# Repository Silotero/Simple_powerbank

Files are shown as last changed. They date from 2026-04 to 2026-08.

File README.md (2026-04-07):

# Simple_powerbank
This is a portable battery bank capable of being charged and discharged at 15W.

The main IC is the MP2722. It does all the heavy lifting. It advertises that it can be sink or source, but mainly trying to be the source to make sure that phones never become sources for it (Retry source function). It takes care of device plugged in detection at the USB-C port and the unplugging of the device to stop the charge. It also is a buck-boost converter, that allows bucks the charge to be suitable for the batteries, as well as boosting the charge for the USB-C output. It can also detect many faults and advertise them to the Attiny404 microcontroller via I2C, after sending an interrupt signal on its interrupt pin.
There is and AP9101CK6 IC that takes care of battery overcharge, overdischarge and short.

The Attiny404 acts as an additional brain for the MP2722 unlocking more of its functions as well as creating a basic user interface. It operates 5 leds. 4 of them indicate the battery charge and the 5th one lights up to indicate if a problem has been detected by the MP2722.
Since the MP2722 has many registers that change how the device behaves, the Attiny404 must set them according to how the user wants the device to operate. At startup the microcontroller sets up all of the registers and then checks them periodically or after an interrupt to see if the device has for some reason reset. If it detects that it writes to the registers again.

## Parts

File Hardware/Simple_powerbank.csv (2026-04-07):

Reference | Qty | Value | DNP | Exclude from BOM | Exclude from Board | Footprint | Datasheet
C1.C3.C4.C6 | 4 | 22u |  |  |  | Capacitor_SMD:C_0603_1608Metric | ~
C2 | 1 | 22n |  |  |  | Capacitor_SMD:C_0603_1608Metric | ~
C5 | 1 | 1u |  |  |  | Capacitor_SMD:C_0603_1608Metric | ~
C7.C8.C16 | 3 | 100n |  |  |  | Capacitor_SMD:C_0603_1608Metric | ~
C9 | 1 | 4.7u |  |  |  | Capacitor_SMD:C_0603_1608Metric | ~
C11.C12.C15.C19 | 4 | 330u |  |  |  | Capacitor_THT:CP_Radial_D6.3mm_P2.50mm | ~
C13 | 1 | 2.2u |  |  |  | Capacitor_SMD:C_0603_1608Metric | ~
C17.C18 | 2 | 220n |  |  |  | Capacitor_SMD:C_0603_1608Metric | ~
D1.D2.D3.D4 | 4 | LED |  |  |  | LED_SMD:LED_0603_1608Metric | ~
D5 | 1 | Problem_led |  |  |  | LED_SMD:LED_0603_1608Metric | ~
D6 | 1 | SMAJ5.0A |  |  |  | Diode_SMD:D_SMA | https://www.littelfuse.com/media?itemid=75e32973-b177-4ee3-a0ff-cedaf1abdb93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
H1.H4 | 2 | Bat- |  | Wyklucz z BOM |  | MountingHole:MountingHole_2.2mm_M2_DIN965_Pad_TopBottom | ~
H2.H3 | 2 | Bat+ |  | Wyklucz z BOM |  | MountingHole:MountingHole_2.2mm_M2_DIN965_Pad_TopBottom | ~
H5.H6.H7.H8 | 4 | MountingHole_Pad |  | Wyklucz z BOM |  | MountingHole:MountingHole_2.2mm_M2_DIN965_Pad | ~
IC1 | 1 | MP2722GRH-0000-Z |  |  |  | MP2722GRH0000Z | https://www.monolithicpower.com/en/documentview/productdocument/index/version/2/document_type/Datasheet/lang/en/sku/MP2722GRH/document_id/10035/
J2 | 1 | USB_C_Receptacle_USB2.0_16P |  |  |  | Connector_USB:USB_C_Receptacle_GCT_USB4105-xx-A_16P_TopMnt_Horizontal | https://www.usb.org/sites/default/files/documents/usb_type-c.zip
J3 | 1 | Programming |  |  |  | Connector_PinHeader_2.54mm:PinHeader_1x03_P2.54mm_Vertical | ~
L1 | 1 | L |  |  |  | Inductor_SMD:L_10.4x10.4_H4.8 | https://www.tme.eu/pl/details/hci1040-4r3/dlawiki/ferrocore/
Q2.Q3 | 2 | NMOS |  |  |  | Package_SO:SOP-8_3.76x4.96mm_P1.27mm | https://ngspice.sourceforge.io/docs/ngspice-html-manual/manual.xhtml
R1.R2.R6.R7.R8 | 5 | 1M |  |  |  | Resistor_SMD:R_0805_2012Metric | ~
R3.R4.R5.R9 | 4 | 10k |  |  |  | Resistor_SMD:R_0805_2012Metric | ~
R10.R11.R12.R13.R14 | 5 | 1k |  |  |  | Resistor_SMD:R_0805_2012Metric | ~
R15 | 1 | 330 |  |  |  | Resistor_SMD:R_0805_2012Metric | ~
R16 | 1 | 2.7k |  |  |  | Resistor_SMD:R_0805_2012Metric | ~
SW1 | 1 | Reset_button |  |  |  | Connector_PinHeader_1.27mm:PinHeader_1x02_P1.27mm_Vertical | ~
TH1 | 1 | 10K |  |  |  | Connector_PinHeader_1.27mm:PinHeader_1x02_P1.27mm_Vertical | ~
U1 | 1 | AP9101CK6 |  |  |  | Package_TO_SOT_SMD:SOT-23-6 | https://www.diodes.com/assets/Datasheets/AP9101C.pdf
U2 | 1 | ATtiny404-SS |  |  |  | Package_SO:SOIC-14_3.9x8.7mm_P1.27mm | http://ww1.microchip.com/downloads/en/DeviceDoc/50002687A.pdf
U4 | 1 | SRV05-4 |  |  |  | Package_TO_SOT_SMD:SOT-23-6 | http://www.onsemi.com/pub/Collateral/SRV05-4-D.PDF

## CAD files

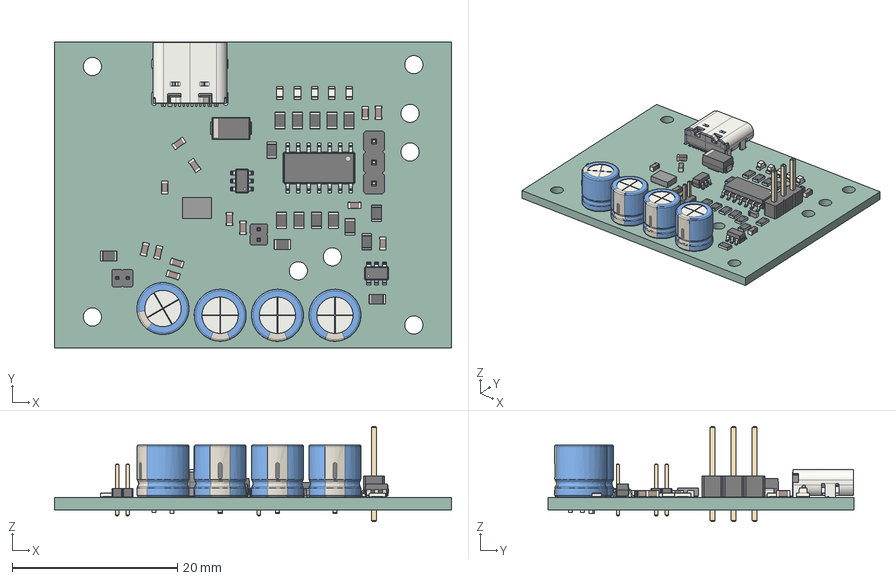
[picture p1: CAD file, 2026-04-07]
Hardware/Simple_powerbank.step
48.0 x 37.0 x 11.5 mm
USB_C_Receptacle_GCT_USB4105-xx-A_16P_TopMnt_Horizontal
R_0805_2012Metric x 16
C_0603_1608Metric x 13
CP_Radial_D6.3mm_P2.50mm x 4
D_SMA
LED_0603_1608Metric x 5
SOIC-14_3.9x8.7mm_P1.27mm
SOT-23-6 x 2
PinHeader_1x02_P1.27mm_Vertical x 2
PinHeader_1x03_P2.54mm_Vertical
Pins
Simple_powerbank_PCB

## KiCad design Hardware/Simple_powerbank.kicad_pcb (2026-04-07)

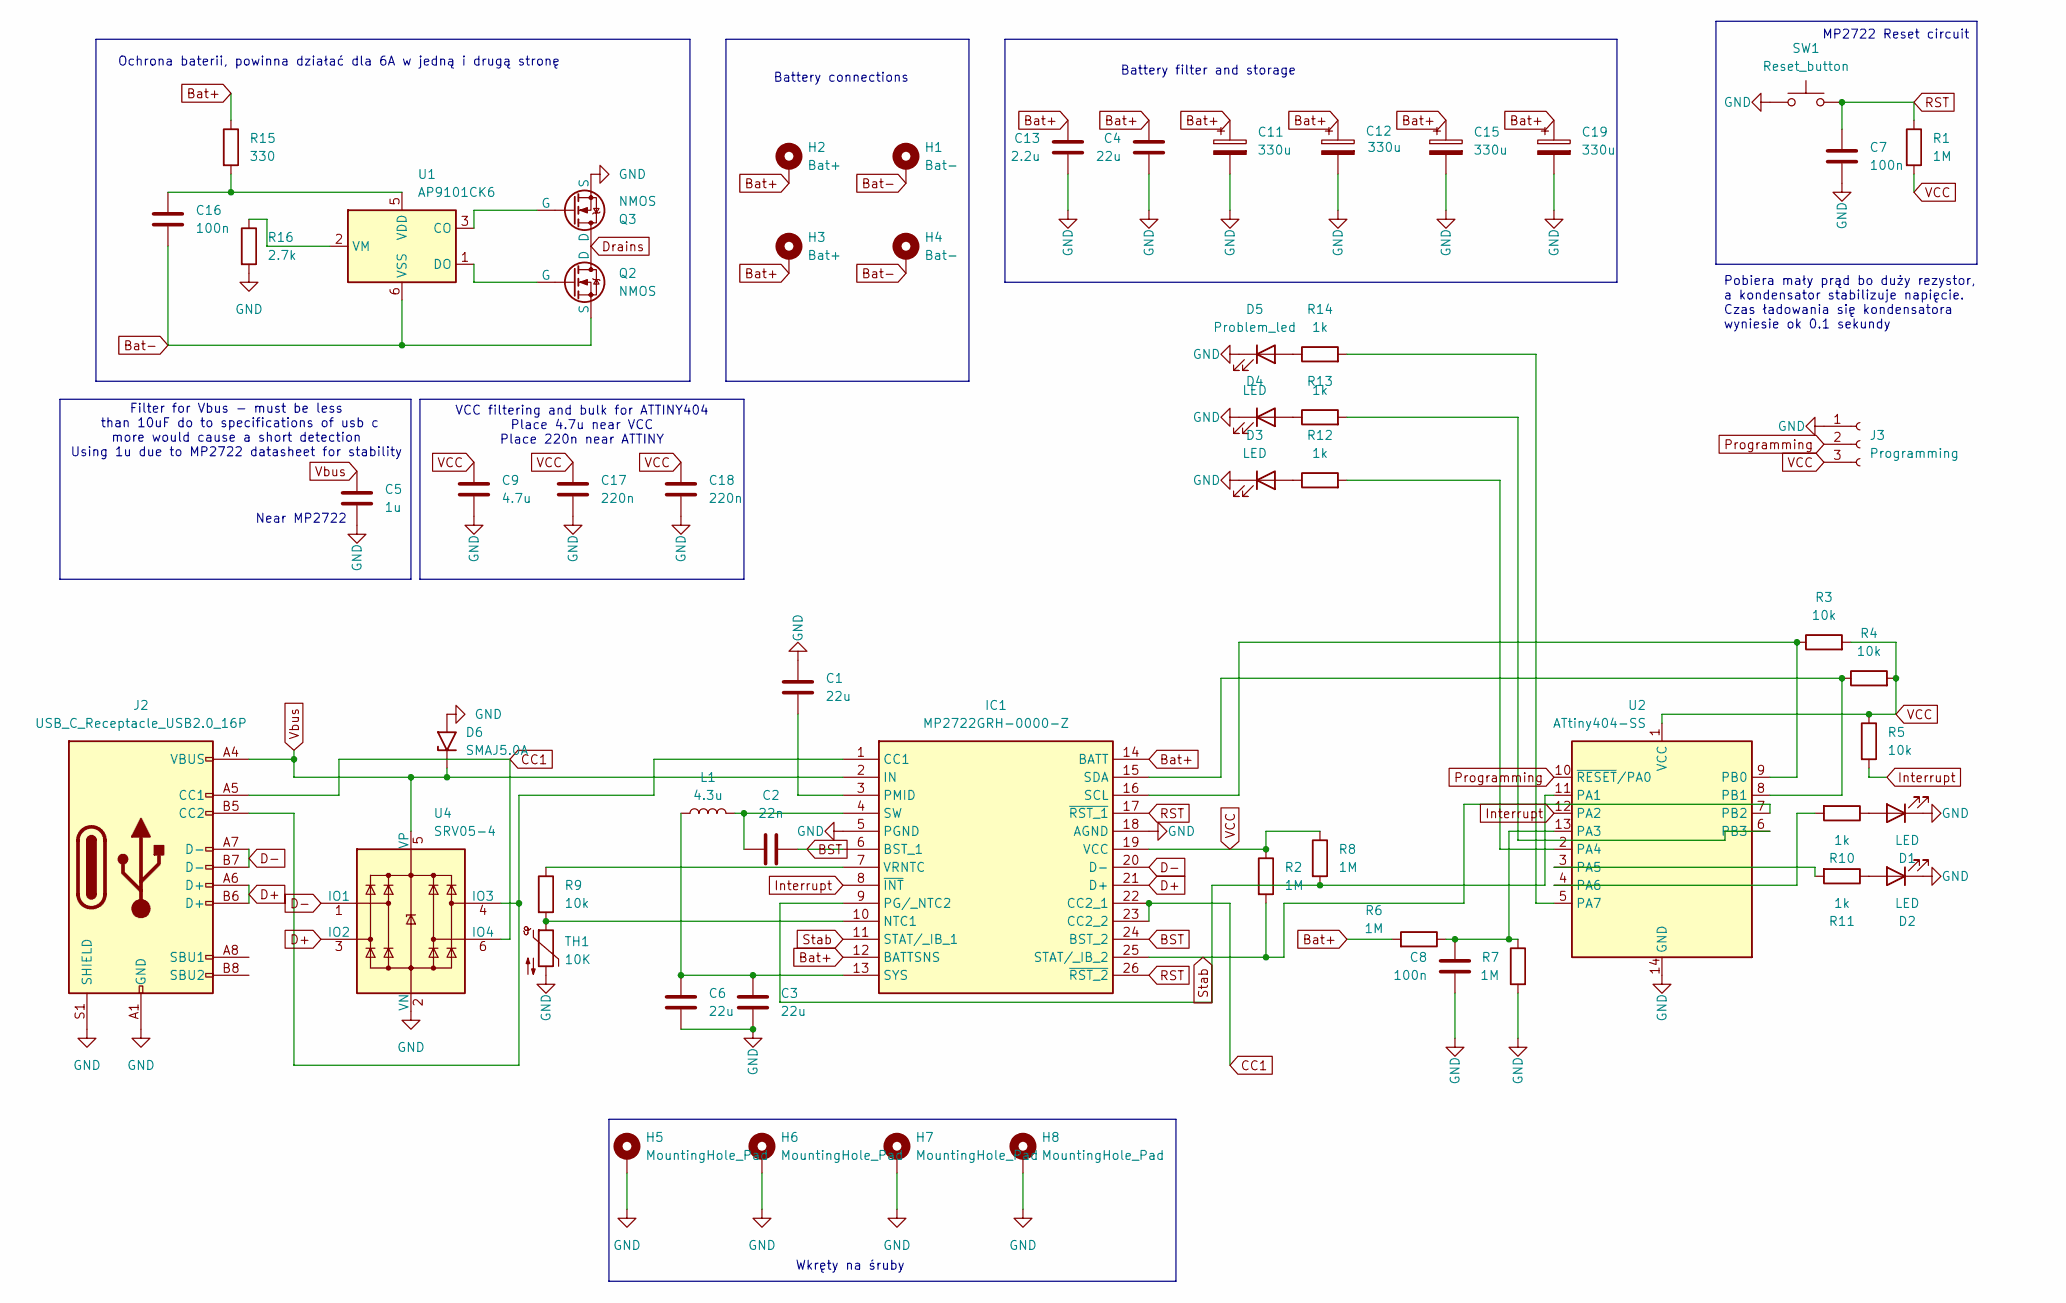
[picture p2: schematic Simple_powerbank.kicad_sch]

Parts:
C1, C3, C4, C6: 22u; C_0603_1608Metric
C2: 22n; C_0603_1608Metric
C5: 1u; C_0603_1608Metric
C7, C8, C16: 100n; C_0603_1608Metric
C9: 4.7u; C_0603_1608Metric
C11, C12, C15, C19: 330u; CP_Radial_D6.3mm_P2.50mm
C13: 2.2u; C_0603_1608Metric
C17, C18: 220n; C_0603_1608Metric
D1, D2, D3, D4: LED; LED_0603_1608Metric
D5: Problem_led; LED_0603_1608Metric
D6: SMAJ5.0A; D_SMA
H1, H4: Bat-; MountingHole_2.2mm_M2_DIN965_Pad_TopBottom
H2, H3: Bat+; MountingHole_2.2mm_M2_DIN965_Pad_TopBottom
H5, H6, H7, H8: MountingHole_Pad; MountingHole_2.2mm_M2_DIN965_Pad
IC1: MP2722GRH-0000-Z; MP2722GRH0000Z; Manufacturer_Part_Number MP2722GRH-0000-Z; Mouser Part Number 946-MP2722GRH-0000-Z
J2: USB_C_Receptacle_USB2.0_16P; USB_C_Receptacle_GCT_USB4105-xx-A_16P_TopMnt_Horizontal
J3: Programming; PinHeader_1x03_P2.54mm_Vertical
L1: 4.3u; L_10.4x10.4_H4.8
Q2, Q3: NMOS; SOP-8_3.76x4.96mm_P1.27mm
R1, R2, R6, R7, R8: 1M; R_0805_2012Metric
R3, R4, R5, R9: 10k; R_0805_2012Metric
R10, R11, R12, R13, R14: 1k; R_0805_2012Metric
R15: 330; R_0805_2012Metric
R16: 2.7k; R_0805_2012Metric
SW1: Reset_button; PinHeader_1x02_P1.27mm_Vertical
TH1: 10K; PinHeader_1x02_P1.27mm_Vertical
U1: AP9101CK6; SOT-23-6
U2: ATtiny404-SS; SOIC-14_3.9x8.7mm_P1.27mm
U4: SRV05-4; SOT-23-6

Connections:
BST: C2.2, IC1.6 (BST_1), IC1.24 (BST_2)
Bat+: C4.2, C11.1, C12.1, C13.2, C15.1, C19.1, H2.1, H3.1, IC1.12 (BATTSNS), IC1.14 (BATT), R6.2, R15.1
Bat-: C16.2, H1.1, H4.1, Q2.3 (S), U1.6 (VSS)
CC1: IC1.22 (CC2_1), IC1.23 (CC2_2), J2.A5 (CC1), U4.6 (IO4)
D+: IC1.21 (D+), J2.A6 (D+), J2.B6 (D+), U4.3 (IO2)
D-: IC1.20 (D-), J2.A7 (D-), J2.B7 (D-), U4.1 (IO1)
Drains: Q2.1 (D), Q3.1 (D)
GND: C1.1, C3.2, C4.1, C5.1, C6.2, C7.2, C8.2, C9.2, C11.2, C12.2, C13.1, C15.2, C17.2, C18.2, C19.2, D1.1 (K), D2.1 (K), D3.1 (K), D4.1 (K), D5.1 (K), D6.2 (A2), H5.1, H6.1, H7.1, H8.1, IC1.5 (PGND), IC1.18 (AGND), J2.A1 (GND), J2.A12 (GND), J2.B1 (GND), J2.B12 (GND), J2.S1 (SHIELD), J3.1, Q3.3 (S), R7.2, R16.2, SW1.1, TH1.2, U2.14 (GND), U4.2 (VN)
Interrupt: IC1.8 (~INT), R5.2, U2.12 (PA2)
unnamed: D1.2 (A), R10.1
unnamed: D2.2 (A), R11.1
unnamed: D3.2 (A), R12.1
unnamed: D4.2 (A), R13.1
unnamed: D5.2 (A), R14.1
unnamed: IC1.1 (CC1), J2.B5 (CC2), U4.4 (IO3)
unnamed: IC1.10 (NTC1), R9.2, TH1.1
unnamed: IC1.9 (PG/_NTC2), R8.2, U2.11 (PA1)
unnamed: C1.2, IC1.3 (PMID)
unnamed: IC1.16 (SCL), R3.1, U2.9 (PB0)
unnamed: IC1.15 (SDA), R4.1, U2.8 (PB1)
unnamed: C2.1, IC1.4 (SW), L1.2
unnamed: C3.1, C6.1, IC1.13 (SYS), L1.1
unnamed: IC1.7 (VRNTC), R9.1
unnamed: Q2.2 (G), U1.1 (DO)
unnamed: Q3.2 (G), U1.3 (CO)
unnamed: C16.1, R15.2, U1.5 (VDD)
unnamed: R16.1, U1.2 (VM)
unnamed: C8.1, R6.1, R7.1, U2.13 (PA3)
unnamed: R12.2, U2.2 (PA4)
unnamed: R11.2, U2.3 (PA5)
unnamed: R10.2, U2.4 (PA6)
unnamed: R14.2, U2.5 (PA7)
unnamed: R13.2, U2.6 (PB3)
Programming: J3.2, U2.10 (~RESET/PA0)
RST: C7.1, IC1.17 (~RST_1), IC1.26 (~RST_2), R1.1, SW1.2
Stab: IC1.11 (STAT/_IB_1), IC1.25 (STAT/_IB_2), R2.2, U2.7 (PB2)
VCC: C9.1, C17.1, C18.1, IC1.19 (VCC), J3.3, R1.2, R2.1, R3.2, R4.2, R5.1, R8.1, U2.1 (VCC)
Vbus: C5.2, D6.1 (A1), IC1.2 (IN), J2.A4 (VBUS), J2.A9 (VBUS), J2.B4 (VBUS), J2.B9 (VBUS), U4.5 (VP)

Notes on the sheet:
Battery filter and storage
Ochrona baterii, powinna działać dla 6A w jedną i drugą stronę
Wkręty na śruby
Battery connections
VCC filtering and bulk for ATTINY404 Place 4.7u near VCC Place 220n near ATTINY
MP2722 Reset circuit
Filter for Vbus - must be less than 10uF do to specifications of usb c more would cause a short detection Using 1u due to MP2722 datasheet for stability
Pobiera mały prąd bo duży rezystor, a kondensator stabilizuje napięcie. Czas ładowania się kondensatora wyniesie ok 0.1 sekundy
Near MP2722

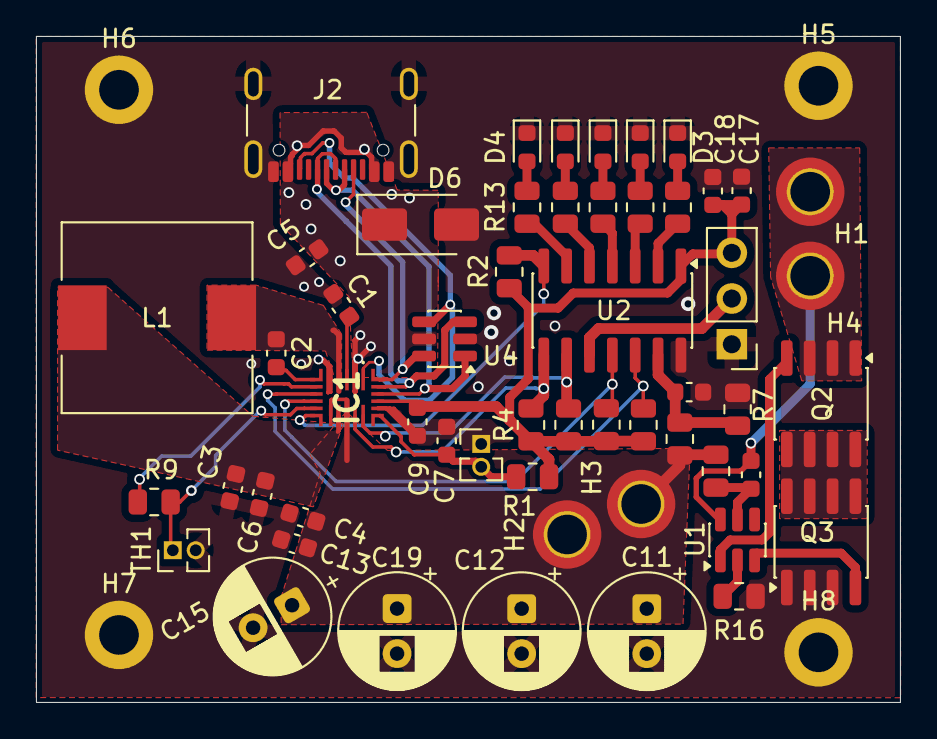
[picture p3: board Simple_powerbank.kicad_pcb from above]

Board: 2 copper layers, 48.0 x 37.0 mm, 58 parts (0 on the bottom side), 38 nets.

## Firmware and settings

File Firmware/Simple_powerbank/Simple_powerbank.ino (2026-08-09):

#include "MP2722.h"
#include <avr/sleep.h>

MP2722 charger;
volatile bool eventDetected = false; // got an interrupt or not

bool faultDetected = false; // read a register, got fault/no fault, used for lighting up fault problem led

const int PIN_BATT  = PIN_PA3;  // Battery divider input
const int Battery_LED_PINS[] = {PIN_PA4, PIN_PA5, PIN_PA6, PIN_PA7}; // LED gpios
const int Problem_LED = PIN_PB3;

// Voltage levels for 1, 2, 3, 4 LEDs
const uint16_t BATT_THRESHOLDS[] = {696, 737, 778, 830}; // Pre-calculated ADC thresholds for: 3.4V, 3.6V, 3.8V, 4.06V

const unsigned long SWITCH_INTERVAL = 2500; // 2500 microseconds = 2.5ms
// Variables for Multiplexing
int currentLedIndex = 0;
unsigned long lastSwitchTime = 0;
unsigned long lastAdcTime = 0;
uint16_t rawAvg = 0;

// The Hardware ISR
// ISR = Interrupt Service Routine
// PORTA_PORT_vect = The hardware address for ANY interrupt on Port A
ISR(PORTA_PORT_vect) {
    // 1. Check WHICH pin fired (Critical if you have multiple interrupts on Port A)
    // We check if the Interrupt Flag (INTFLAGS) for Pin 2 is set, since that is where the interrupt from the MP2722 is connected
    if (PORTA.INTFLAGS & PIN2_bm) {
        
        // 2. Set the eventDetected to true to use it later
        eventDetected = true;

        // 3. Clear the Interrupt Flag (CRITICAL!)
        // Writing '1' to the flag bit aclears it
        // If not cleared, the interrupt will fire again immediately forever.
        PORTA.INTFLAGS = PIN2_bm; 
    }
}

void setup() {
    //Start I2C on the attiny404
    Wire.begin();
    //PORTB.DIRSET = PIN2_bm; // stat pin, read to find out if pinB2
    // Setting up the interrupt
    PORTA.DIRCLR = PIN2_bm; // Assuming INT is on PA2, set up as input
    PORTA.PIN2CTRL = PORT_ISC_FALLING_gc; // to read the falling edge on interrupt pin

    PORTA.DIRSET = PIN4_bm | PIN5_bm | PIN6_bm | PIN7_bm;
    PORTB.DIRSET = PIN3_bm; // Setting up the leds pins as outputs

    PORTA.OUTCLR = PIN4_bm | PIN5_bm | PIN6_bm | PIN7_bm;
    PORTB.OUTCLR = PIN3_bm; // Setting low output for the led pins

    PORTA.DIRCLR = PIN3_bm; // PIN_PA3 set as input, for reading battery voltage divider
    // 1. Set Voltage Reference to Internal 2.5V
    // (Replaces analogReference(INTERNAL2V5))
    VREF.CTRLA |= VREF_ADC0REFSEL_2V5_gc;
    // 2. Configure the ADC Prescaler
    // We want the ADC clock to be between 50kHz and 1.5MHz.
    // Assuming 20MHz CPU clock, DIV32 gives ~625kHz.
    ADC0.CTRLC = ADC_PRESC_DIV16_gc; // or DIV16_gc if running at 10MHz
    // 3. Enable the ADC (10-bit resolution is default)
    ADC0.CTRLA = ADC_ENABLE_bm | ADC_RESSEL_10BIT_gc;

    // 2. Start Charger
    if (charger.wasReset()) {
        charger.begin();
    }

    // setup the sleep workarounds of the attiny404
    set_sleep_mode(SLEEP_MODE_PWR_DOWN); 
}

void loop() {
    static unsigned long last_sleep_check = 0;
    unsigned long current_millis = millis();
    showBatteryLevel();
    // 1. Handle Events
    if (eventDetected) {
        eventDetected = false;
        if (charger.processInterrupt()) {
            faultDetected = true;
        }
        else faultDetected = false;
    }

    if (faultDetected) {
        digitalWrite(Problem_LED, (current_millis / 250) % 2); // Fast blink the problem indicating led
    }

    // 2. Periodically check "Canary" (in case Watchdog reset happened silently)
    static unsigned long lastCheck = 0;
    if (current_millis - lastCheck > 10000) {
        if (charger.wasReset()) {
            charger.begin(); // Re-apply settings
        }
        lastCheck = current_millis;
    }
    
    if (current_millis - last_sleep_check > 15000) {
        if (!charger.isChargingDischarging()) {
            PORTA.OUTCLR = PIN4_bm | PIN5_bm | PIN6_bm | PIN7_bm;
            PORTB.OUTCLR = PIN3_bm;
            charger.gotosleep();
        }
        last_sleep_check = current_millis;
    }
}

void showBatteryLevel() { // this lights up battery indicator leds
    // 1. Read ADC
    // We take a few samples and average them to remove noise
    unsigned long currentMicros = micros();
    if (currentMicros - lastAdcTime >= 500000) { 
        lastAdcTime = currentMicros;
        uint16_t rawSum = 0;
        for(uint8_t i = 0; i < 4; i++) {
            rawSum += readBatteryADC(); // Direct hardware read
        }
        rawAvg = rawSum >> 2;
        if (rawAvg > 850) {
             if (charger.FinishedCharging()) VPORTB.OUT |= PIN3_bm;
        }
    }

    // 3. Update LEDs
    // Workings of the battery indication: the leds gets cycled so only one is actually on at a time, the leds light up based on if the battery level is higher than the set level for the charge. If the charge is below 3.4 the first leds flickers
    if (currentMicros - lastSwitchTime >= SWITCH_INTERVAL) {
        lastSwitchTime = currentMicros;

        currentLedIndex++;
        if (currentLedIndex >= 4) {
            currentLedIndex = 0;
        }

        // 2. Clear ALL LEDs (Atomic & Fast)
        // Instead of looping to find which ones to turn off, just kill them all.
        // LEDs are on PA4, PA5, PA6, PA7
        PORTA.OUTCLR = PIN4_bm | PIN5_bm | PIN6_bm | PIN7_bm;

        // 3. Logic: Should the CURRENT LED be ON?
        bool shouldTurnOn = false;

        // SPECIAL CASE: Critical Low Battery (Blink LED 0)
        if (currentLedIndex == 0 && rawAvg < 696) {
            // ">> 8" divides by 256. "& 1" keeps the last bit (odd/even).
            // Result: A perfect ~256ms blink with NO division library.
            if ((millis() >> 8) & 1) shouldTurnOn = true;
        }
        // NORMAL CASE: Check Voltage Threshold
        else if (rawAvg >= BATT_THRESHOLDS[currentLedIndex]) {
            shouldTurnOn = true;
        }

        // 4. Execute: Turn ON the specific LED using VPORT
        if (shouldTurnOn) {
            switch (currentLedIndex) {
                case 0: VPORTA.OUT |= PIN4_bm; break; // PA4
                case 1: VPORTA.OUT |= PIN5_bm; break; // PA5
                case 2: VPORTA.OUT |= PIN6_bm; break; // PA6
                case 3: VPORTA.OUT |= PIN7_bm; break; // PA7
            }
        }
    }
}

uint16_t readBatteryADC() { // quick analog pin that can be used strictly for the one pin of my battery
    // 1. Select the Input Channel (AIN3 is PA3)
    ADC0.MUXPOS = ADC_MUXPOS_AIN3_gc; 

    // 2. Start Conversion
    ADC0.COMMAND = ADC_STCONV_bm; 

    // 3. Wait for result (Blocking, but very fast ~20us)
    while (!(ADC0.INTFLAGS & ADC_RESRDY_bm)); 

    // 4. Return the result
    return ADC0.RES; 
}

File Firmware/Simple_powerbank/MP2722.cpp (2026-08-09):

#include "MP2722.h"
#include <avr/sleep.h>
MP2722::MP2722(uint8_t address) {
    _addr = address; // Save the address so writeReg can use it later
}

const uint8_t STARTUP_CONFIG[13] = {
    0x10,
    0x04,
    0xFF,
    0xFF,
    0xBC,
    0x18,
    0x0C,
    0x0F,
    0x7E,
    0x4B,
    0x28,
    0x10,
    0x1F
};

bool MP2722::begin() {
    // 1. "Ping" the chip
    // Try to read the Part ID (or any static register)
    Wire.beginTransmission(_addr);
    if (Wire.endTransmission() != 0) {
        return false; // NO REPLY! Wiring is wrong or chip is dead.
    }

    // 2. Chip is alive! Now configure it.
    writeBurst(0x00, 13, (uint8_t*)STARTUP_CONFIG);
    writeReg(0x10, 0x39);

    return true; // Success
}

void MP2722::gotosleep() {
    sleep_enable();
    sei();
    sleep_cpu();
    sleep_disable();
}

bool MP2722::FinishedCharging() {
    if (readReg(0x13) & 0xA0) {
        return 1;
    }
    return 0;
}

bool MP2722::isChargingDischarging() {
    uint8_t status_registers[2]; 
    status_registers[0] = readReg(0x13); // charge status, checking if charge is happening or is done but plugged in
    status_registers[1] = readReg(0x09); // checks if boost is enabled, meaning it is charging a device
    if (status_registers[0] & 0xE0 || status_registers[1] & 0x04) { // checks whether charging or discharging is happening
        return 1;
    }
    return 0;
}

bool MP2722::processInterrupt() { // Set what happens when the pulse was detected on interrupt pin
    uint8_t status_registers = readReg(0x13); // charge status, boost fault, charge fault status register

    // --- Decode the Status ---

    if (status_registers & 0x10) {
        gotosleep(); // battery low interrupt was sent, boost was turned off, put device to sleep
        return 0;
    }

    if (status_registers & 0x0F) { // input source not valid or booost/charger faults, excluding boost stopped due to batt low
        return 1;
    }
    return 0;
}

// Check if the chip might have reset by checking if one of the registers permanent settings have changed
bool MP2722::wasReset() {
    uint8_t check_register = readReg(REG_VBOOST);
    if (check_register == REG_VBOOST_PERMANENT_SETTINGS)
    {
        return 0;
    }
    return 1;
}

// void MP2722::handlePlugEvent(uint8_t dpdm, uint8_t cc) {
//     // 1. Check for High Voltage Adapter (Samsung/QC)
//     // DPDM_STAT 1001 = High Voltage
//     if (((dpdm >> 4) & 0x0F) == 0x09) {
//         // Found a Fast Charger! Request 9V.
//         requestHighVoltage();
//     }
    
//     // 2. Check for USB-C 3.0A
//     // CC_STAT 11 = vRd-3.0
//     else if ((cc & 0x03) == 0x03 || (cc & 0xC0) == 0xC0) {
//         // Pure USB-C 3A. Set limit to 3.0A
//         setInputCurrent(3.0);
//     }
    
//     // 3. Fallback (Standard USB)
//     else {
//         setInputCurrent(2.0); // Or safe default
//     }
// }

// void MP2722::requestHighVoltage() {
//     // Write 01 to HVREQ (Bits 1:0 of Reg 0x0B)
//     // This asks for 9V.
//     uint8_t val = readReg(REG_HV_CTRL);
//     writeReg(REG_HV_CTRL, (val & 0xFC) | 0x01);
// }

// bool MP2722::checkMoisture() {
//     // 1. Enable Current Source (Bit 6)
//     // You'll need the register address for VIN_SRC_EN (Reg 0x0F usually)
//     uint8_t regVal = readReg(0x0F);
//     writeReg(0x0F, regVal | 0x40);
    
//     delay(10); // Wait for stabilization

//     // 2. Read ADC (Pseudo-code, check datasheet for ADC reg)
//     // If voltage is > 0.5V but < 4.0V, it's likely water.
//     // float voltage = readADC(ADC_VIN); 

//     // 3. Disable Current Source
//     writeReg(0x0F, regVal & ~0x40);

//     // return (voltage > 0.5 && voltage < 4.0);
//     return false; // Placeholder
// }

// ---------------------------------------------------------
// Private Helper: Write a single byte to a specific register
// ---------------------------------------------------------
void MP2722::writeReg(uint8_t reg, uint8_t val) {
    Wire.beginTransmission(_addr); // Start talking to MP2722
    Wire.write(reg);               // Say: "I want to write to this Register"
    Wire.write(val);               // Say: "Here is the value"
    Wire.endTransmission();        // Stop talking
}

// Private Helper: Write multiple bytes to the registers
void MP2722::writeBurst(uint8_t startReg, uint8_t length, uint8_t* data) {
    Wire.beginTransmission(_addr);
    Wire.write(startReg); // Tell chip where to start writing (e.g., Reg 0x01)
    
    // Loop through the array and send bytes one by one
    // The MP2722 auto-increments the address internally after each byte
    for (uint8_t i = 0; i < length; i++) {
        Wire.write(data[i]);
    }
    
    Wire.endTransmission();
}

// ---------------------------------------------------------
// Private Helper: Read a single byte from a register
// ---------------------------------------------------------
uint8_t MP2722::readReg(uint8_t reg) {
    // Step 1: Tell the chip WHICH register we want to read
    Wire.beginTransmission(_addr);
    Wire.write(reg);
    Wire.endTransmission(false); // "false" means send a Restart, not a Stop (keeps connection alive)

    // Step 2: Request 1 byte of data
    Wire.requestFrom(_addr, (uint8_t)1);
    
    // Step 3: Grab the byte
    if (Wire.available()) {
        return Wire.read();
    }
    return 0; // Return 0 if communication failed
}

// ---------------------------------------------------------
// Private Helper: Read multiple bytes at once (Burst Read)
// ---------------------------------------------------------
void MP2722::readBurst(uint8_t startReg, uint8_t count, uint8_t* buffer) {
    // Step 1: Tell the chip where to start reading
    Wire.beginTransmission(_addr);
    Wire.write(startReg);
    Wire.endTransmission(false); // Restart

    // Step 2: Request 'count' bytes
    Wire.requestFrom(_addr, count);

    // Step 3: Read them all into the array
    for (uint8_t i = 0; i < count; i++) {
        if (Wire.available()) {
            buffer[i] = Wire.read();
        } else {
            buffer[i] = 0; // Safety for failed reads
        }
    }
}

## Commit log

2026-04-07 Added finished project kicad files and the code files
    [Simple_powerbank.csv, Simple_powerbank.kicad_pcb, Simple_powerbank.kicad_sch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]
2026-05-22 Zmieniono wartości kondensatorów
    [Simple_powerbank.kicad_sch]
2026-08-09 Working sample
    [Simple_powerbank.kicad_sch]
